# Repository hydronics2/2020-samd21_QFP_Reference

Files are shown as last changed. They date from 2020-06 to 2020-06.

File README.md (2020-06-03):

# samd21_QFP_reference_PCB - based on the Adafruit ItsyBitsy M0

This is a reference design for a SAMD21 for easy SWD programming and testing.  This is a copy of the [Adafruit itsyBitsy m0](https://www.adafruit.com/product/3727)... Using the SAMD21G QFP package among other small part changes. It does not include the memory module for circuit python use. This is similar to the other QFP packages with less memory that I was working with [here](https://github.com/hydronics2/samd21_QFP_reference_PCB).

The QFP package is pretty easy to solder and gives you about the same amount of pins as the original Aruduino 328P.

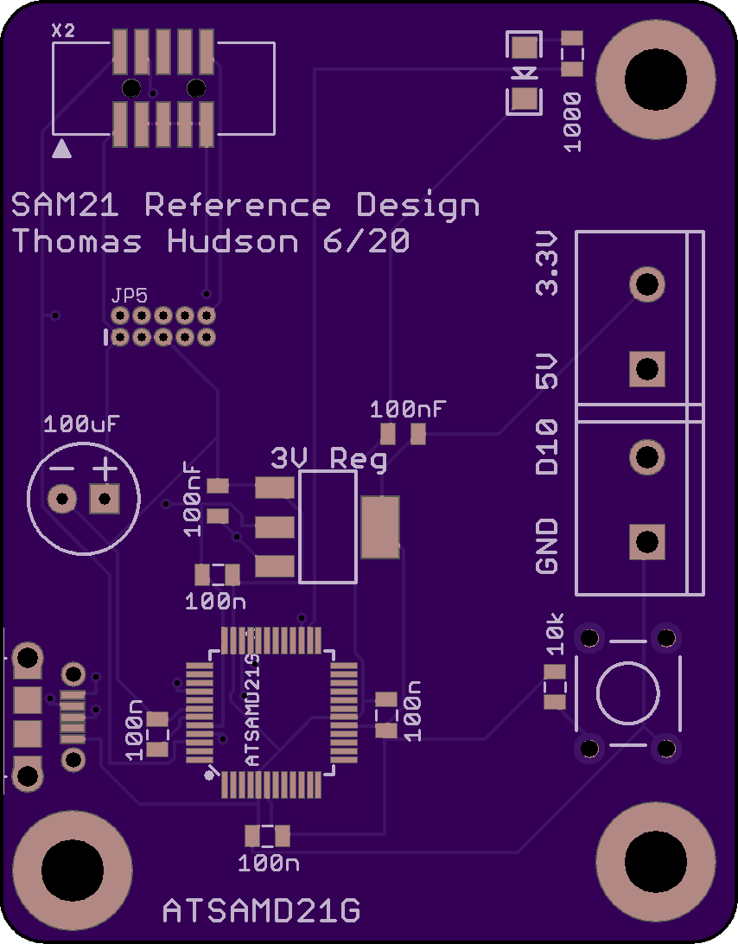
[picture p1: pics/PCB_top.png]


You can order boards from Oshpark using this link: [project](https://oshpark.com/shared_projects/W1OeQO5j)

Here's a list of parts:
- ATSAMD21G from [digikey](https://www.digikey.com/product-detail/en/microchip-technology/ATSAMD21G18A-AUT/ATSAMD21G18A-AUTCT-ND/4878879).
  -	ARM® Cortex®-M0+ SAM D21G Microcontroller IC 32-Bit 48MHz 256KB (256K x 8) FLASH 48-TQFP (7x7)
- 10 pin SWD Header
  - I included an SMD version [mouser](https://www.mouser.com/ProductDetail/485-752)
  - an even cooler SMD version [mouser](https://www.mouser.com/ProductDetail/485-4048)
  - and a through hole version [mouser](https://www.mouser.com/ProductDetail/200-SHF10501LDTH)
- 3.3V Regulator - generic (18V max input) [mouser](https://www.mouser.com/ProductDetail/511-LDL1117S50R)
- USB micro connector [digikey](https://www.digikey.com/product-detail/en/amphenol-icc-fci/10118194-0001LF/609-4618-1-ND/2785382)
- generic 6mmx6mm tactile button [sparkfun](https://www.sparkfun.com/products/97)
- screw terminal 5mm pitch [sparkfun](https://www.sparkfun.com/products/8432) or [aliexpress](https://www.aliexpress.com/wholesale?catId=0&initiative_id=SB_20190221221755&SearchText=pcb+screw+terminal)

SWD Programmer/Debugger: [Segger](https://www.digikey.com/product-detail/en/segger-microcontroller-systems/8.08.91-J-LINK-EDU-MINI/899-1061-ND/7387472)

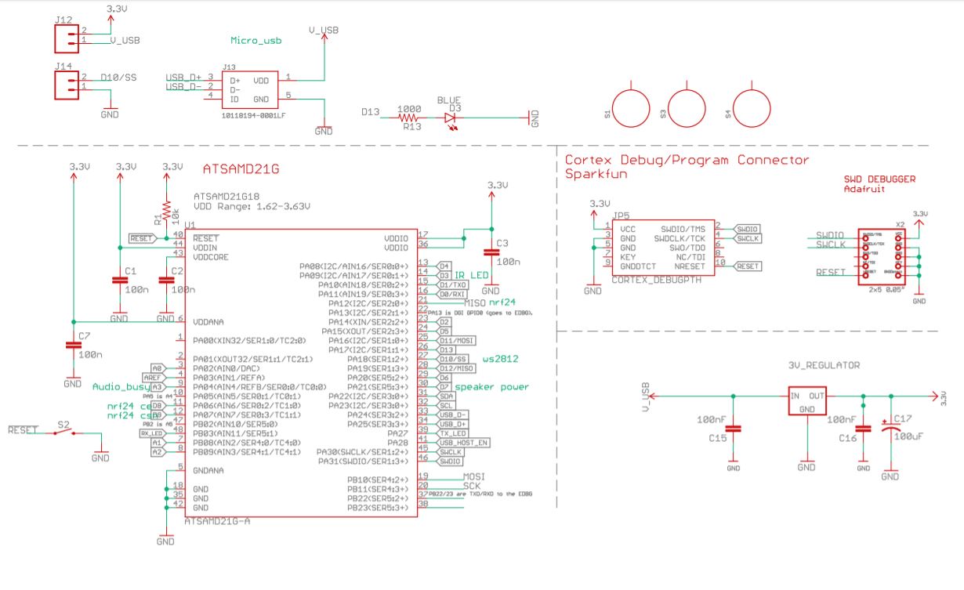
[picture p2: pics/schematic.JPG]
schematic


## Programming

Adafruit has provided a great [tutorial](https://learn.adafruit.com/how-to-program-samd-bootloaders) for flashing the bootloader onto the board using the segger SWD programmer. It's easier than it looks.

You probably already have the bootloader loader on your computer! Arduino installs them when you install the board files.

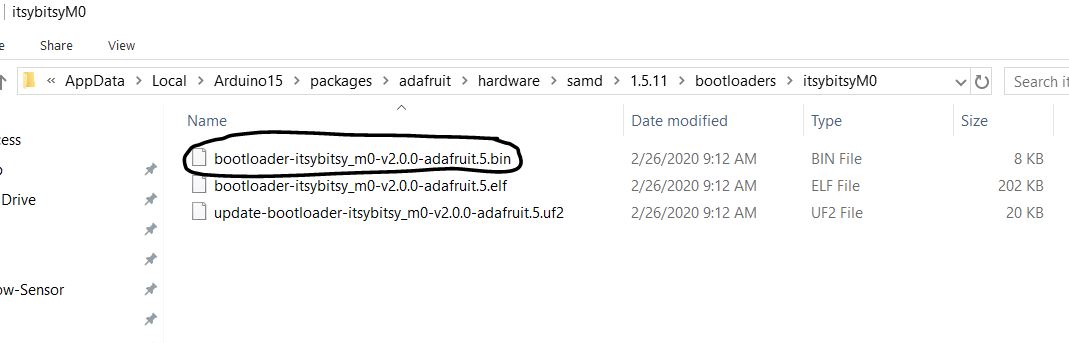
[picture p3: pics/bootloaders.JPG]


# Projects - Pickathon Music Festival

I completed a project at [Pickathon 2019 music festival](https://www.instagram.com/p/B0nMJXHBQjl/) using radio modules and MP3 Players that socketed into a PCB very similar to the reference design above.

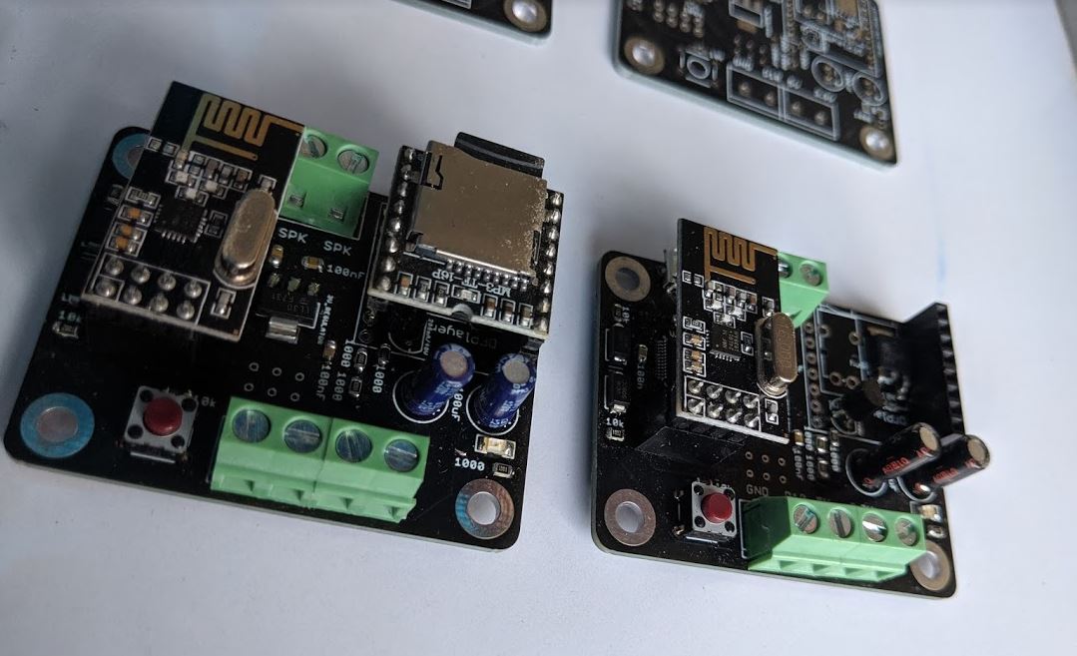
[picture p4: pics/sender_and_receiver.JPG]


Both the sender and receiver boards had radio modules socketed into an SPI header that was exposed via a 8-pin header.
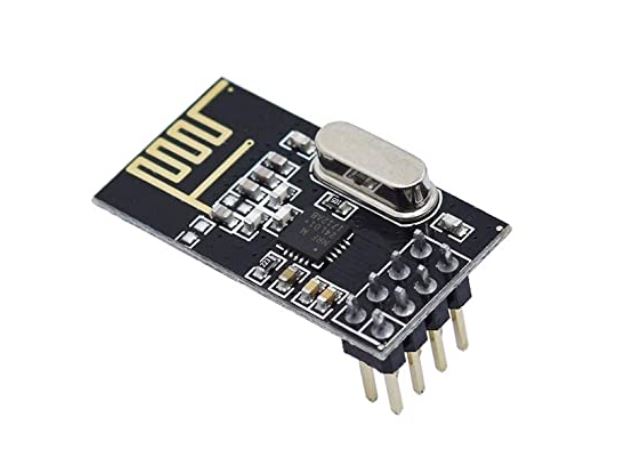
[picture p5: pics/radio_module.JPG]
radio


Each receiver board had a mini-MP3 module. When triggered, the MP3 modules output recorded poetry files to small speakers. The MP3 modules worked really well. The 3-watt amplifier sounded pretty good with small speakers in quiet spaces.
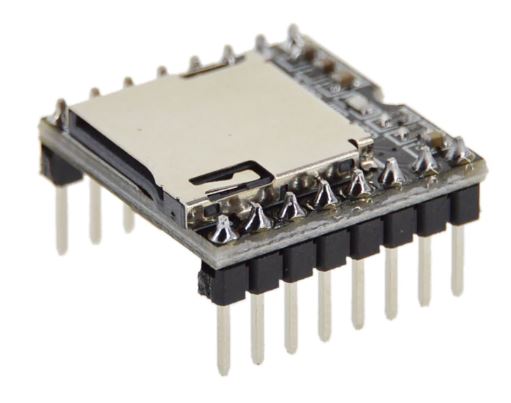
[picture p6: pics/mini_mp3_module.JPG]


## Parts list
- generic Radio module Arduino NRF24L01+ 2.4GHz Wireless RF [amazon](https://www.amazon.com/gp/product/B07GZ17ZWS/ref=ppx_yo_dt_b_asin_title_o01_s00?ie=UTF8&psc=1)
- generic Mini-MP3 module [aliexpress](https://www.aliexpress.com/item/32787304159.html?spm=a2g0s.9042311.0.0.27424c4dwHyDU7)

## Programming

The radio module library is here:
- include <nRF24L01.h>  //https://github.com/nRF24/RF24

The MP3 radio module is here:
- include <DFPlayerMini_Fast.h>  //https://github.com/PowerBroker2/DFPlayerMini_Fast

I slightly modified the DFPlayerMini library so it would work with hardware serial and not software serial as it was originally designed.

The micro-controller communicated with the MP3 player using serial RX/TX.

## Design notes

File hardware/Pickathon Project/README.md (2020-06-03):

## Pickathon Hardware

Instead of including a standard SWD programming header, I only exposed the pins at places that would except a custom programming PCB with pogo pins..... so this PCB design (as-is) is probably  not useful to anyone but easy to manipulate.

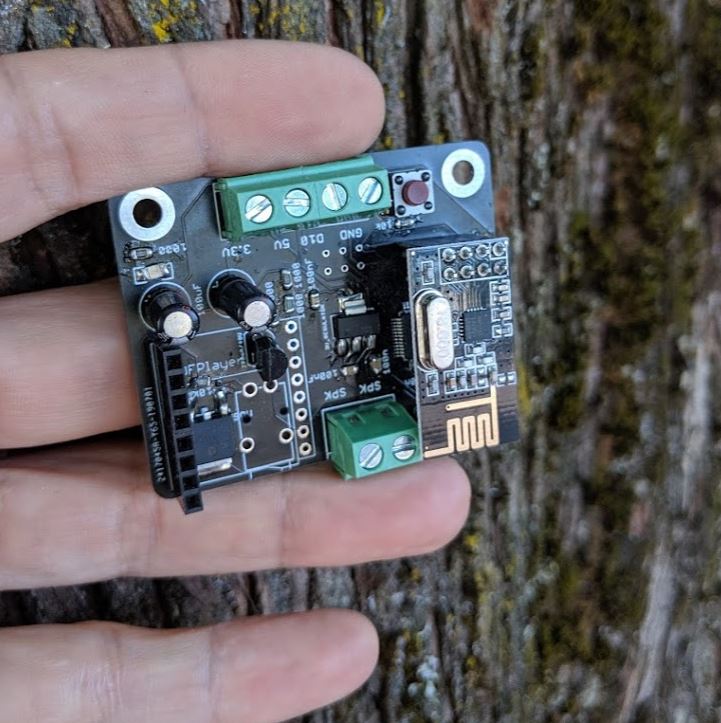
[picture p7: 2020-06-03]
pics/sender_module.JPG

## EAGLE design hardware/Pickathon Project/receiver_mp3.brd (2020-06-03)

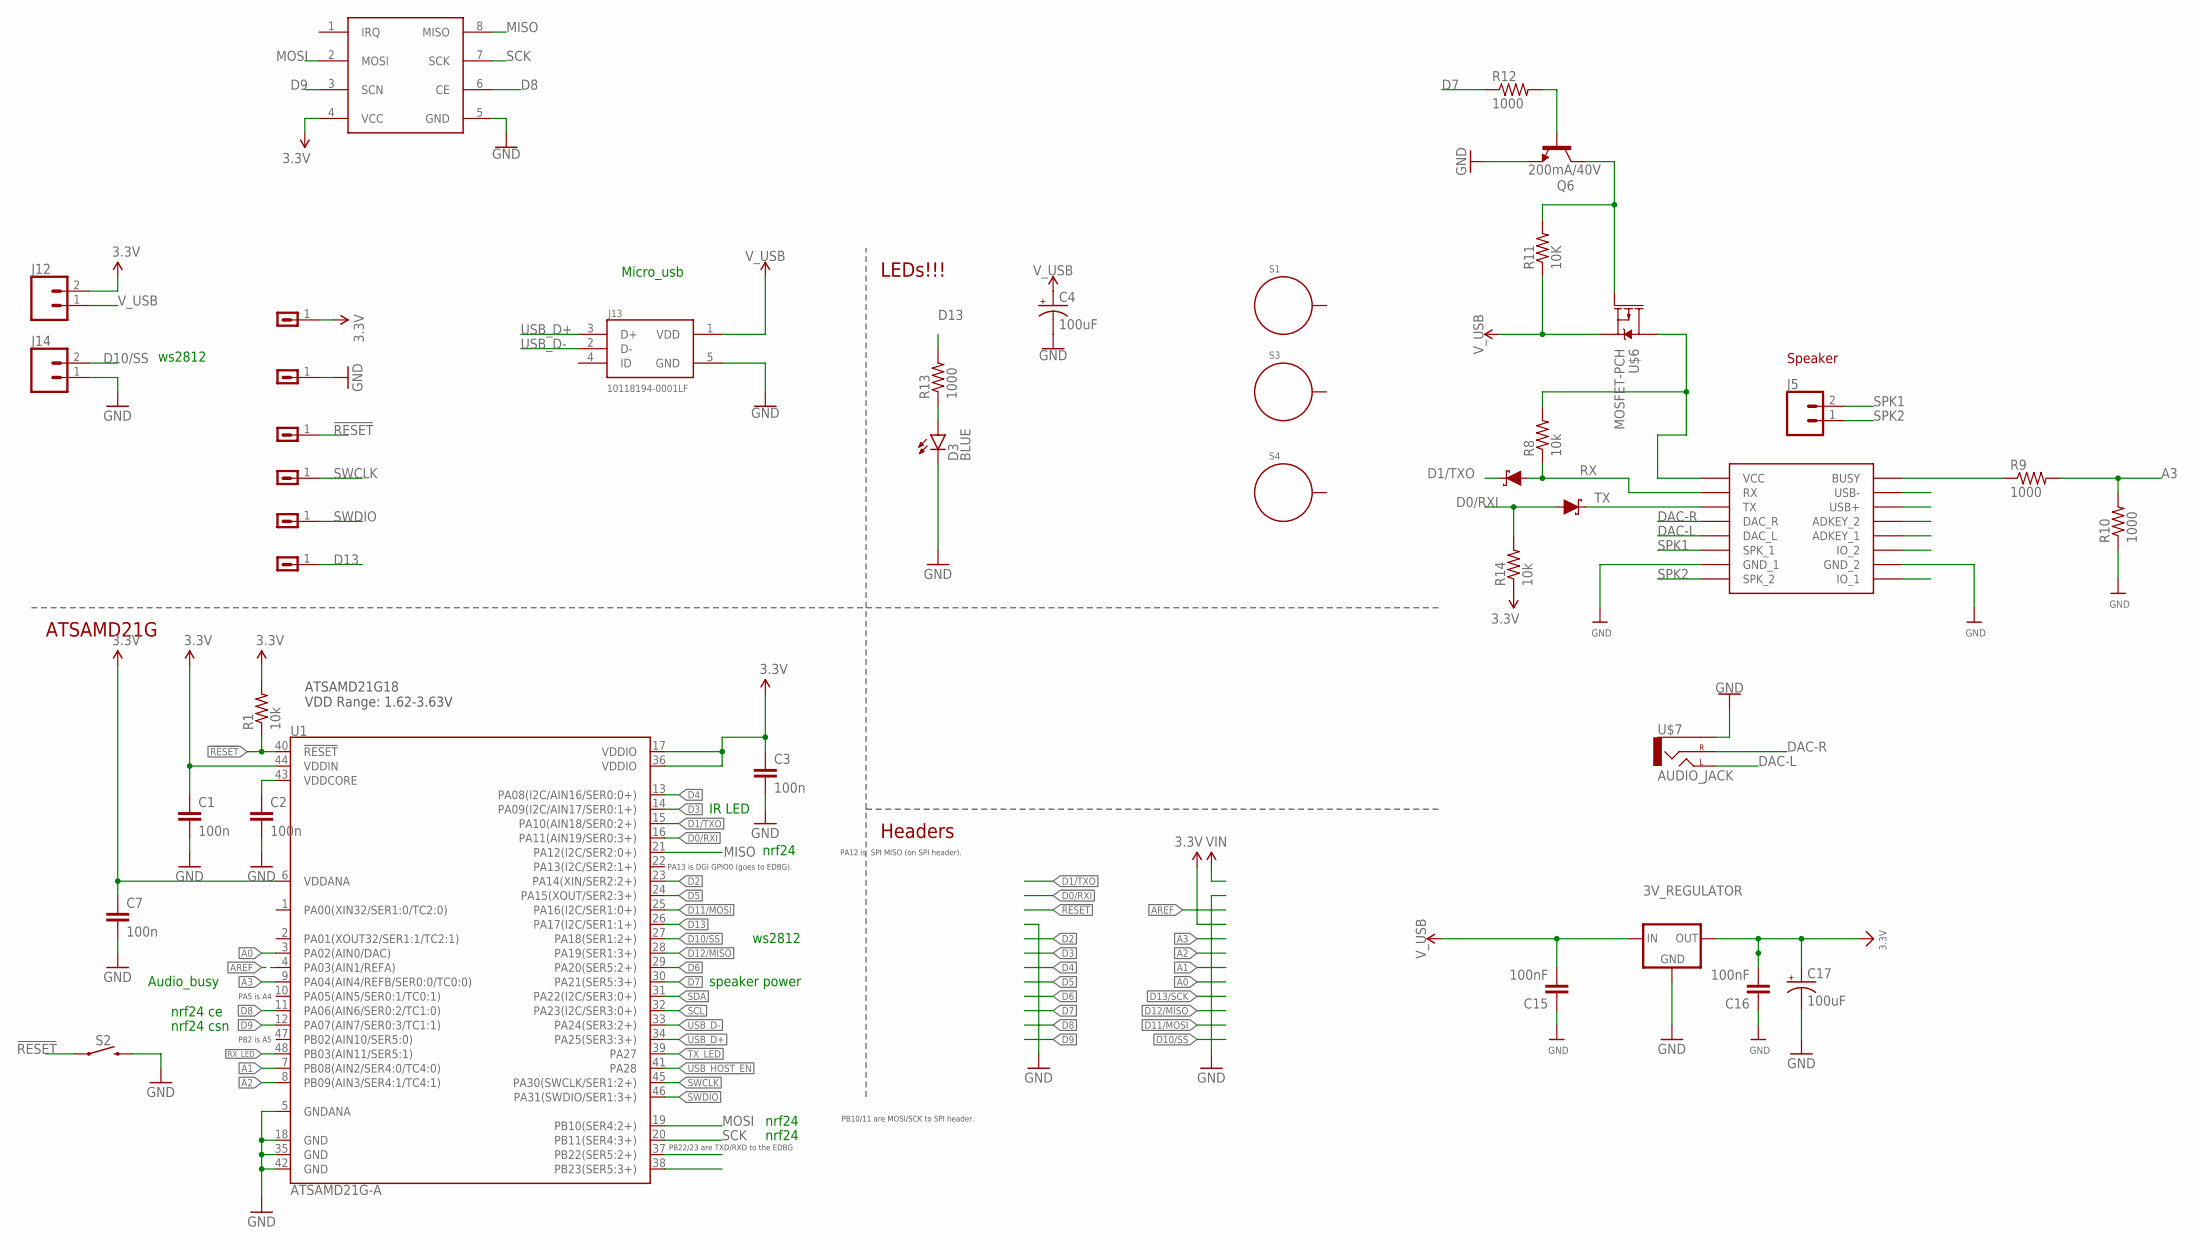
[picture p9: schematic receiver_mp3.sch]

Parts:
3V_REGULATOR: LDL1117_5V_REG; SOT223
C1, C2, C3, C7: 100n; 0805
C4, C17: 100uF; CPOL-RADIAL-2.5MM-6.5MM
C15, C16: 100nF; 0805
D1, D5: 3A/40V/500mV; SMA-DIODE
D3: BLUE; LED-1206
J5, J12, J14: CONN_025MM; SCREWTERMINAL-5MM-2
J13: 10118194-0001LF; FRAMATOME_10118194-0001LF
Q6: 200mA/40V; TO-92-EZ
R1, R8, R14: 10k; 0805
R9, R10, R12, R13: 1000; 0805
R11: 10K; 0805
S1, S3, S4: STANDOFF_ELECTRICAL144; STANDOFF_ELECTRICAL_144MILL_NORMAL_SCREW
S2: MOMENTARY-SWITCH-SPST-PTH-6.0MM-KIT; TACTILE_SWITCH_PTH_6.0MM_KIT
U1: ATSAMD21G-A; TQFP-48
U$1: DFPLAYER
U$3: NRF24L01
U$6: MOSFET-PCH; DPAK
U$7: AUDIO_JACK; 1/8"AUDIO_JACK
U$8, U$13, U$18, U$19, U$20, U$22: CONN_011.27MM; 1X01-1.27MM

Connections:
3.3V: 3V_REGULATOR.2 (OUT), 3V_REGULATOR.4 (OUT), C1.1, C3.1, C7.1, C16.2, C17.1 (+), J12.2, R1.2, R14.1, U1.6 (VDDANA), U1.17 (VDDIO), U1.36 (VDDIO), U1.44 (VDDIN), U$3.4 (VCC), U$18.1
!RESET: R1.1, S2.1, U1.40 (!RESET!), U$20.1
A0: U1.3 (PA02(AIN0/DAC))
A1: U1.7 (PB08(AIN2/SER4:0/TC4:0))
A2: U1.8 (PB09(AIN3/SER4:1/TC4:1))
A3: R9.2, R10.2, U1.9 (PA04(AIN4/REFB/SER0:0/TC0:0))
AREF: U1.4 (PA03(AIN1/REFA))
D0/RXI: D5.A, R14.2, U1.16 (PA11(AIN19/SER0:3+))
D1/TXO: D1.C, U1.15 (PA10(AIN18/SER0:2+))
D2: U1.23 (PA14(XIN/SER2:2+))
D3: U1.14 (PA09(I2C/AIN17/SER0:1+))
D4: U1.13 (PA08(I2C/AIN16/SER0:0+))
D5: U1.24 (PA15(XOUT/SER2:3+))
D6: U1.29 (PA20(SER5:2+))
D7: R12.1, U1.30 (PA21(SER5:3+))
D8: U1.11 (PA06(AIN6/SER0:2/TC1:0)), U$3.6 (CE)
D9: U1.12 (PA07(AIN7/SER0:3/TC1:1)), U$3.3 (SCN)
D10/SS: J14.2, U1.27 (PA18(SER1:2+))
D11/MOSI: U1.25 (PA16(I2C/SER1:0+))
D12/MISO: U1.28 (PA19(SER1:3+))
D13: R13.2, U1.26 (PA17(I2C/SER1:1+)), U$8.1
DAC-L: U$1.DAC_L, U$7.LEFT_TIP_1 (LEFT)
DAC-R: U$1.DAC_R, U$7.RIGHT
GND: 3V_REGULATOR.1 (GND), C1.2, C2.2, C3.2, C4.2 (-), C7.2, C15.1, C16.1, C17.2 (-), D3.C, J13.5 (GND), J14.1, Q6.1 (E), R10.1, S2.3 (2), U1.5 (GNDANA), U1.18 (GND), U1.35 (GND), U1.42 (GND), U$1.GND_1, U$1.GND_2, U$3.5 (GND), U$7.GND (SLEEVE), U$13.1
INT1: U1.38 (PB23(SER5:3+))
MISO: U1.21 (PA12(I2C/SER2:0+)), U$3.8 (MISO)
MOSI: U1.19 (PB10(SER4:2+)), U$3.2 (MOSI)
unnamed: R8.2, U$1.VCC, U$6.4 (D)
unnamed: D3.A, R13.1
unnamed: Q6.3 (C), R11.2, U$6.1 (G)
unnamed: Q6.2 (B), R12.2
unnamed: R9.1, U$1.BUSY
RX: D1.A, R8.1, U$1.RX
RX_LED: U1.48 (PB03(AIN11/SER5:1))
SCK: U1.20 (PB11(SER4:3+)), U$3.7 (SCK)
SCL: U1.32 (PA23(I2C/SER3:0+))
SDA: U1.31 (PA22(I2C/SER3:0+))
SPK1: J5.2, U$1.SPK1 (SPK_1)
SPK2: J5.1, U$1.SPK2 (SPK_2)
SWCLK: U1.45 (PA30(SWCLK/SER1:2+)), U$22.1
SWDIO: U1.46 (PA31(SWDIO/SER1:3+)), U$19.1
TX: D5.C, U$1.TX
TX_LED: U1.39 (PA27)
USB_D+: J13.3 (D+), U1.34 (PA25(SER3:3+))
USB_D-: J13.2 (D-), U1.33 (PA24(SER3:2+))
USB_HOST_EN: U1.41 (PA28)
VDDCORE: C2.1, U1.43 (VDDCORE)
V_USB: 3V_REGULATOR.3 (IN), C4.1 (+), C15.2, J12.1, J13.1 (VDD), R11.1, U$6.3 (S)

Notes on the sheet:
PB22/23 are TXD/RXD to the EDBG
PB10/11 are MOSI/SCK to SPI header.
PA12 is SPI MISO (on SPI header).
PA13 is DGI GPIO0 (goes to EDBG).
PA5 is A4
PB2 is A5
LEDs!!!
Headers
ATSAMD21G
ATSAMD21G18 VDD Range: 1.62-3.63V
Micro_usb
IR LED
speaker power
Speaker
Audio_busy
ws2812
nrf24
nrf24 csn
nrf24 ce

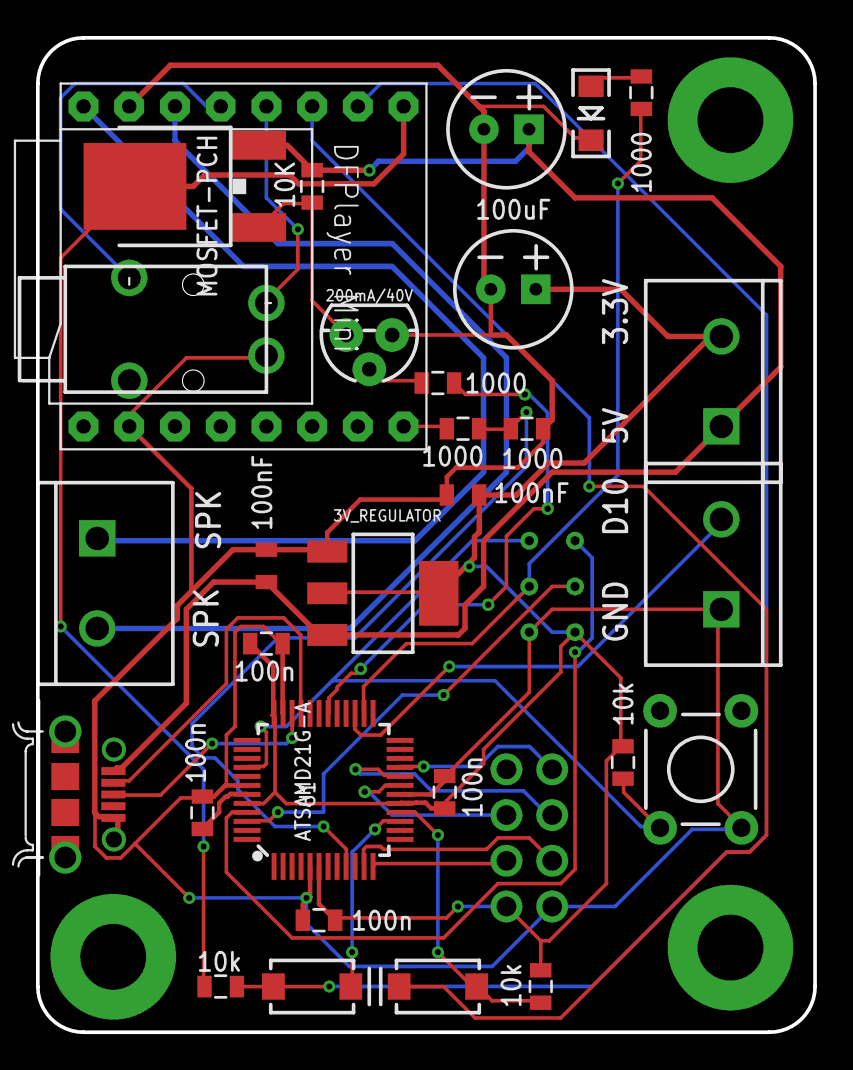
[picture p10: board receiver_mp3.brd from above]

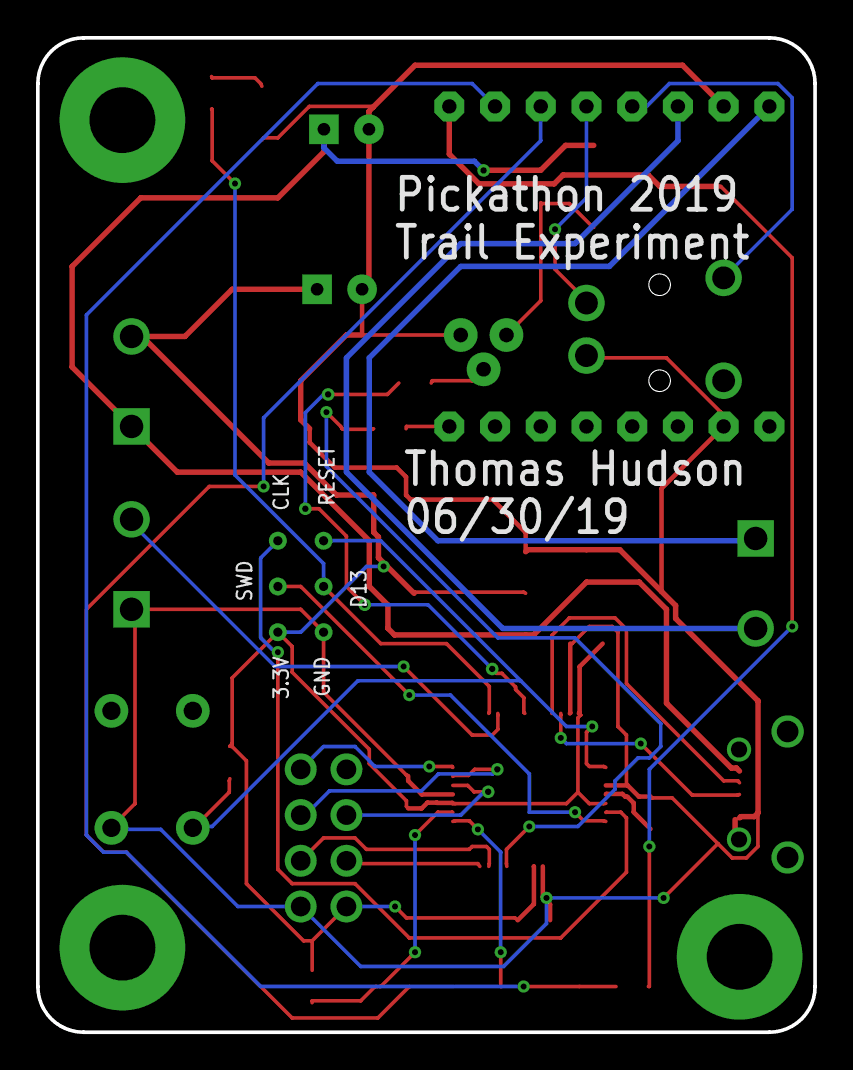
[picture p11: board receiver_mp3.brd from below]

Board: 2 copper layers, 43.2 x 55.2 mm, 40 parts (6 on the bottom side), 31 nets.

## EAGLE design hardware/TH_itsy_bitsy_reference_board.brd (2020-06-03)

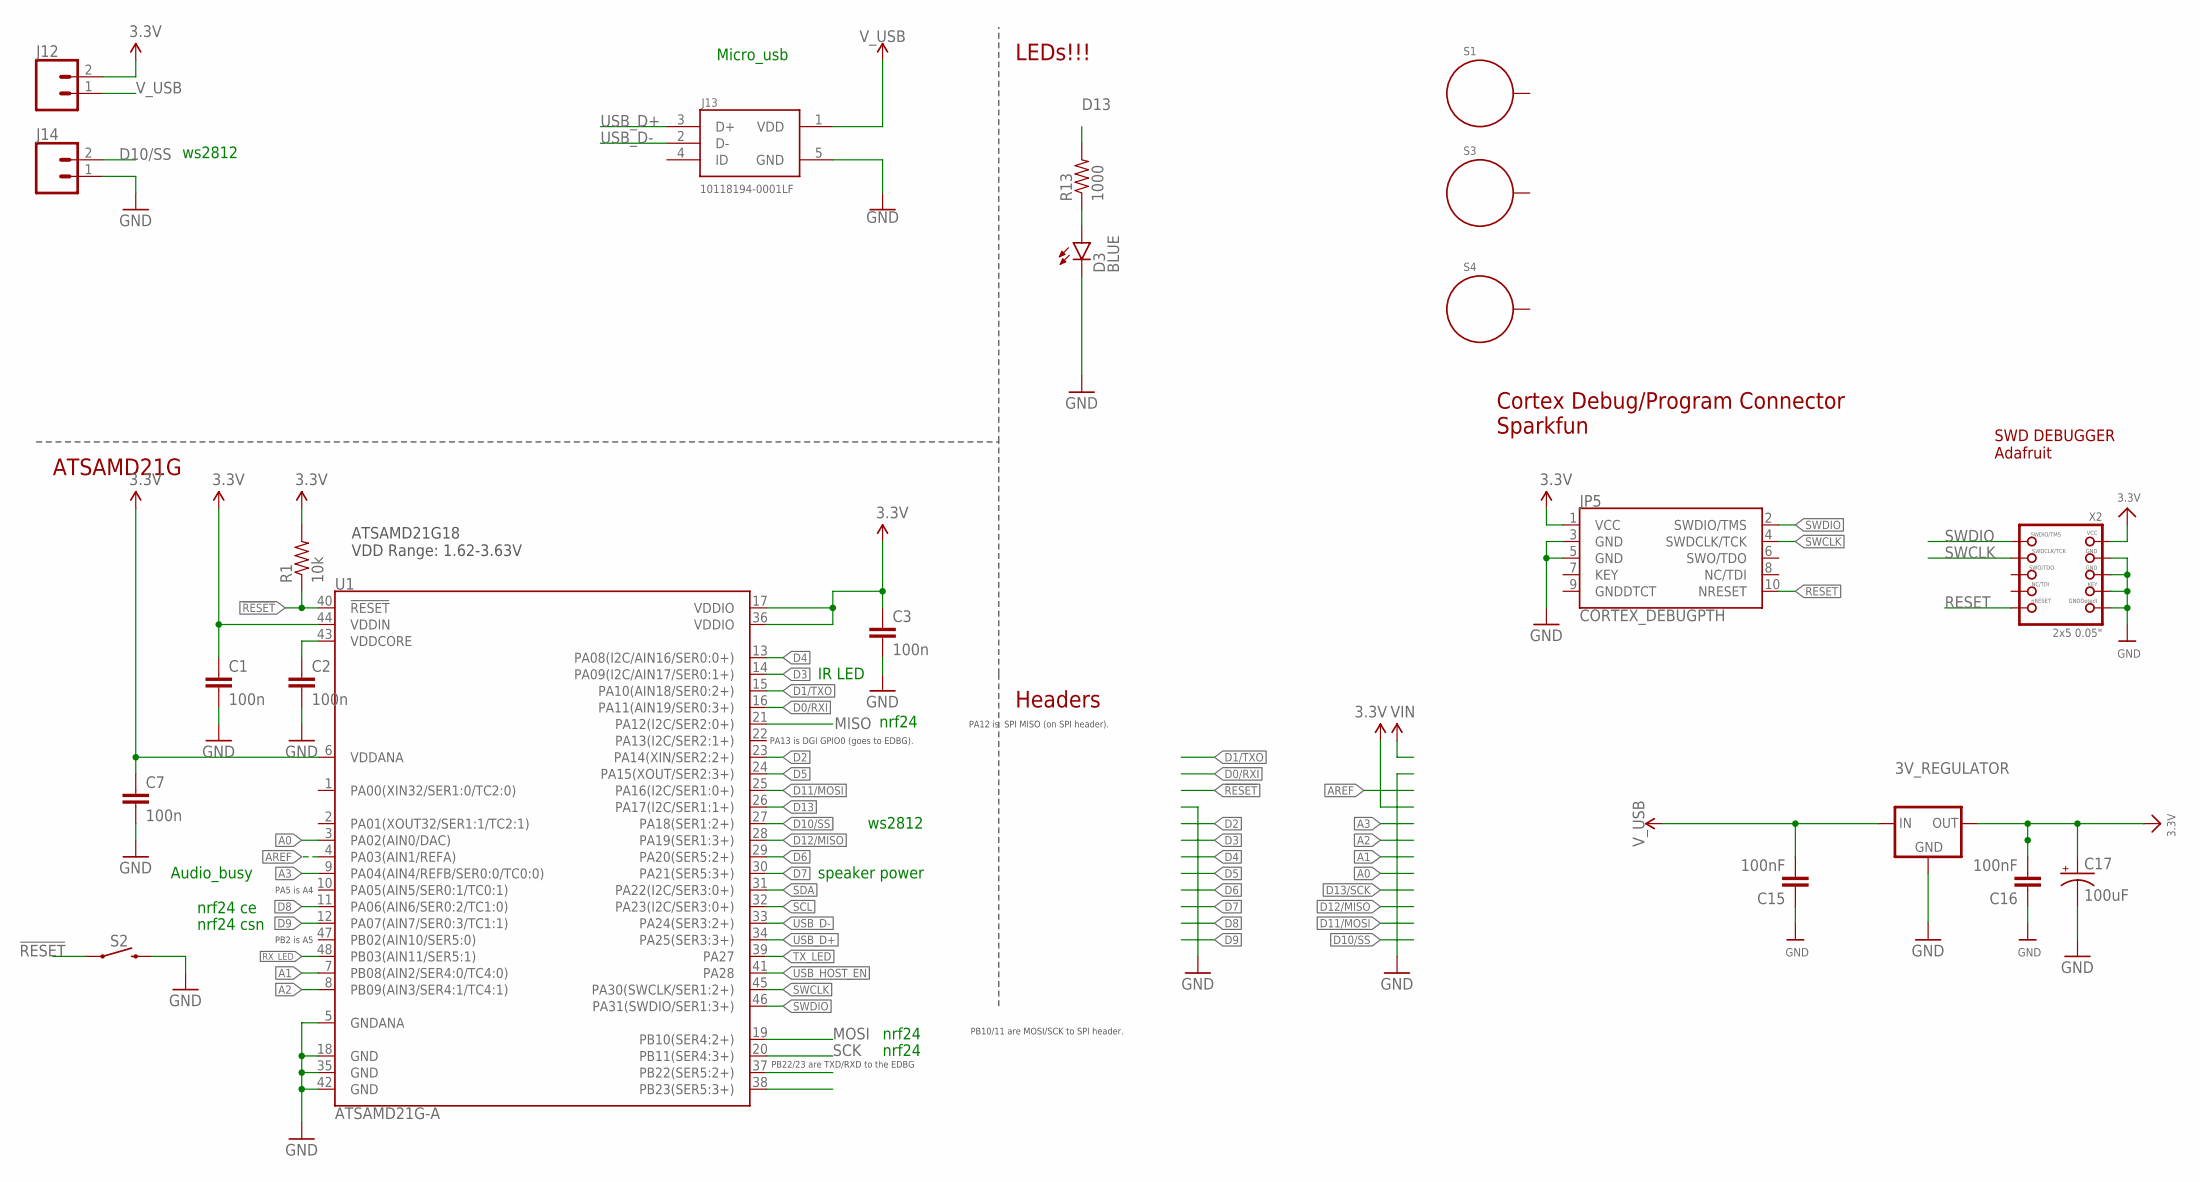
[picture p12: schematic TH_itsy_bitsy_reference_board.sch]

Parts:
3V_REGULATOR: LDL1117_5V_REG; SOT223
C1, C2, C3, C7: 100n; 0805
C15, C16: 100nF; 0805
C17: 100uF; CPOL-RADIAL-2.5MM-6.5MM
D3: BLUE; LED-1206
J12, J14: CONN_025MM; SCREWTERMINAL-5MM-2
J13: 10118194-0001LF; FRAMATOME_10118194-0001LF
JP5: CORTEX_DEBUGPTH; 2X5-PTH-1.27MM
R1: 10k; 0805
R13: 1000; 0805
S1, S3, S4: STANDOFF_ELECTRICAL144; STANDOFF_ELECTRICAL_144MILL_NORMAL_SCREW
S2: MOMENTARY-SWITCH-SPST-PTH-6.0MM-KIT; TACTILE_SWITCH_PTH_6.0MM_KIT
U1: ATSAMD21G-A; TQFP-48
X2: 2x5 0.05"; 2X05_1.27MM_BOX_POSTS

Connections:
3.3V: 3V_REGULATOR.2 (OUT), 3V_REGULATOR.4 (OUT), C1.1, C3.1, C7.1, C16.2, C17.1 (+), J12.2, JP5.1 (VCC), R1.2, U1.6 (VDDANA), U1.17 (VDDIO), U1.36 (VDDIO), U1.44 (VDDIN), X2.1 (VCC)
!RESET: R1.1, S2.1, U1.40 (!RESET!)
A0: U1.3 (PA02(AIN0/DAC))
A1: U1.7 (PB08(AIN2/SER4:0/TC4:0))
A2: U1.8 (PB09(AIN3/SER4:1/TC4:1))
A3: U1.9 (PA04(AIN4/REFB/SER0:0/TC0:0))
AREF: U1.4 (PA03(AIN1/REFA))
D0/RXI: U1.16 (PA11(AIN19/SER0:3+))
D1/TXO: U1.15 (PA10(AIN18/SER0:2+))
D2: U1.23 (PA14(XIN/SER2:2+))
D3: U1.14 (PA09(I2C/AIN17/SER0:1+))
D4: U1.13 (PA08(I2C/AIN16/SER0:0+))
D5: U1.24 (PA15(XOUT/SER2:3+))
D6: U1.29 (PA20(SER5:2+))
D7: U1.30 (PA21(SER5:3+))
D8: U1.11 (PA06(AIN6/SER0:2/TC1:0))
D9: U1.12 (PA07(AIN7/SER0:3/TC1:1))
D10/SS: J14.2, U1.27 (PA18(SER1:2+))
D11/MOSI: U1.25 (PA16(I2C/SER1:0+))
D12/MISO: U1.28 (PA19(SER1:3+))
D13: R13.2, U1.26 (PA17(I2C/SER1:1+))
GND: 3V_REGULATOR.1 (GND), C1.2, C2.2, C3.2, C7.2, C15.1, C16.1, C17.2 (-), D3.C, J13.5 (GND), J14.1, JP5.3 (GND), JP5.5 (GND), S2.3 (2), U1.5 (GNDANA), U1.18 (GND), U1.35 (GND), U1.42 (GND), X2.3 (GND), X2.5 (GND), X2.7 (KEY), X2.9 (GNDDETECT)
INT1: U1.38 (PB23(SER5:3+))
MISO: U1.21 (PA12(I2C/SER2:0+))
MOSI: U1.19 (PB10(SER4:2+))
unnamed: D3.A, R13.1
RESET: JP5.10 (NRESET), X2.10 (NRESET)
RX_LED: U1.48 (PB03(AIN11/SER5:1))
SCK: U1.20 (PB11(SER4:3+))
SCL: U1.32 (PA23(I2C/SER3:0+))
SDA: U1.31 (PA22(I2C/SER3:0+))
SWCLK: JP5.4 (SWDCLK/TCK), U1.45 (PA30(SWCLK/SER1:2+)), X2.4 (SWDCLK)
SWDIO: JP5.2 (SWDIO/TMS), U1.46 (PA31(SWDIO/SER1:3+)), X2.2 (SWDIO)
TX_LED: U1.39 (PA27)
USB_D+: J13.3 (D+), U1.34 (PA25(SER3:3+))
USB_D-: J13.2 (D-), U1.33 (PA24(SER3:2+))
USB_HOST_EN: U1.41 (PA28)
VDDCORE: C2.1, U1.43 (VDDCORE)
V_USB: 3V_REGULATOR.3 (IN), C15.2, J12.1, J13.1 (VDD)

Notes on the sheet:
PB22/23 are TXD/RXD to the EDBG
PB10/11 are MOSI/SCK to SPI header.
PA12 is SPI MISO (on SPI header).
PA13 is DGI GPIO0 (goes to EDBG).
PA5 is A4
PB2 is A5
LEDs!!!
Headers
ATSAMD21G
ATSAMD21G18 VDD Range: 1.62-3.63V
Micro_usb
IR LED
speaker power
Audio_busy
ws2812
nrf24
nrf24 csn
nrf24 ce
SWD DEBUGGER Adafruit
Cortex Debug/Program Connector Sparkfun

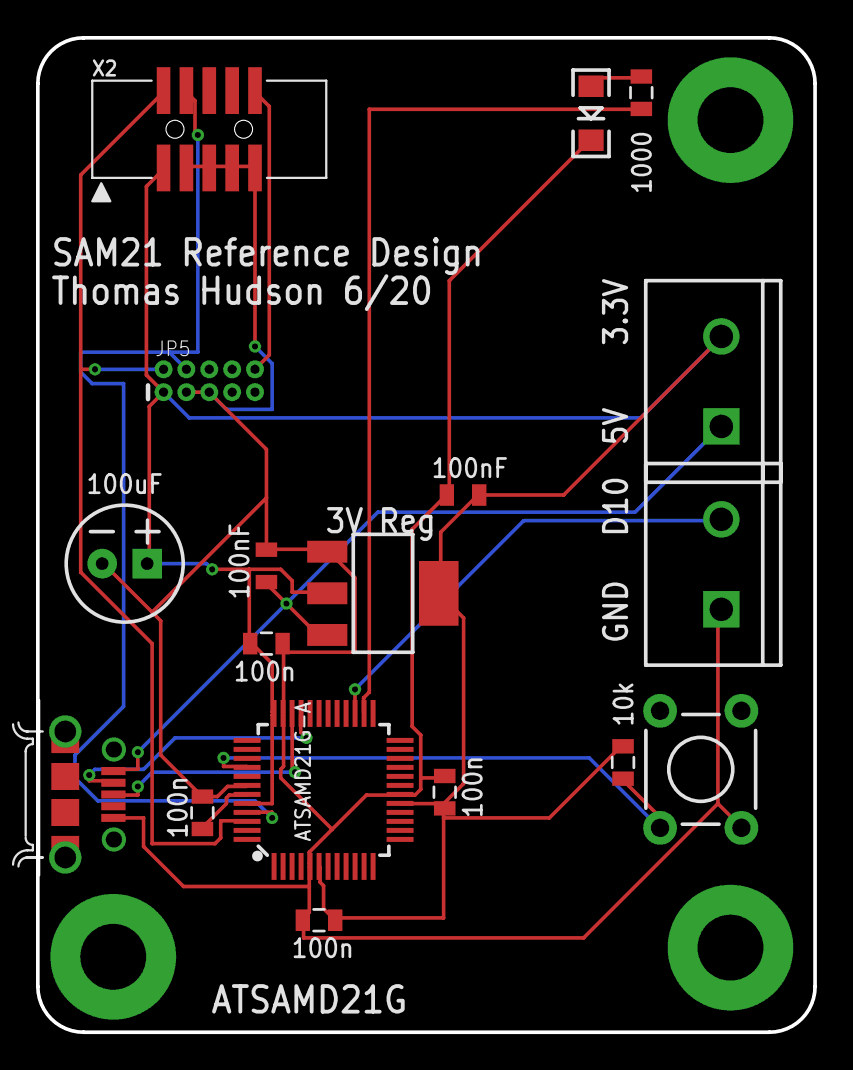
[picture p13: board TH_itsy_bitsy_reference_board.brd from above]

Board: 2 copper layers, 43.2 x 55.2 mm, 21 parts (0 on the bottom side), 13 nets.

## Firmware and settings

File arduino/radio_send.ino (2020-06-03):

const int playerNumber = 0; //speaker 0, 1st speaker


#include <SPI.h>
#include <nRF24L01.h>  //https://github.com/nRF24/RF24
#include <RF24.h>

#include <DFPlayerMini_Fast.h>  //https://github.com/PowerBroker2/DFPlayerMini_Fast

DFPlayerMini_Fast myMP3; 

RF24 radio(8,9); //CE and CSN

const byte address[6] = "00001";
const int motionSensorPin = 10;
const int mp3PowerPin = 7;
const int led = 13;

//poem info... indicates the SD card file number for each poem.. 
int poemInfo [][8] = {  {1,2,3,4,5,6,0,0}, //time for bed - 6 lines 
                        {7,8,9,10,11,0,0,0}, //oleander - 5 lines 
                        {12,13,14,15,0,0,0,0}, // its cool - 4 lines 
                        {16,17,18,19,20,21,0,0}, //tonight I could do anything - 6 lines
                        {22, 23, 24, 25, 26, 27, 0, 0}, //you're a bird to the treasure - 6 lines
                        {28,29,30,31,32,33, 0, 0}, //tamborine - 6 lines
                        {34,35,36,37,38,39, 0, 0}, //wildfire
                        {40,41,42,43,44,45, 0, 0}, //william berry
                        
};

int poemSectionDelays [][8] = { {3000,3000,3000,3000,3000,3000,0,0}, //time for bed - 6 lines 
                                {3000,3000,3000,3000,3000,0,0,0}, //oleander - 5 lines 
                                {3000,3000,3000,3000,0,0,0,0}, // its cool - 4 lines 
                                {12000,8000,7000,5000,4000,4000,0,0}, //tonight I could do anything
                                {2000,5000,5000,6000,6000,5000,0,0}, //you're a bird to the treasure
                                {8000,3000,7000,12000,11000,8000,0,0}, //tamborine
                                {4000,15000,12000,23000,4000,11000,0,0}, //wildfire
                                {11000,13000,8000,8000,8000,12000,0,0}, //william berry
};

//                                     1     2     3     4   5
byte poemSectionStartDelays [][6] = { {0x4, 0x7, 0x0A, 0x0D, 0x10, 0x0}, //time for bed - 6 lines 
                                      {0x4, 0x7, 0x8, 0x9, 0x0, 0x0}, //oleander - 5 lines 
                                      {0X4, 0x6, 0x8, 0x0, 0x0, 0x0}, // its cool - 4 lines 
                                      {0x0B, 0x13, 0x18, 0x1B, 0x1E, 0x0}, //tonight I could do anything
                                      {0x3, 0x7, 0x0A, 0x0E, 0x13, 0x0}, //you're a bird to the treasure
                                      {0x8, 0x0A, 0x10, 0x19, 0x22, 0x0}, //tamborine                                      
                                      {0x4, 0x11, 0x1B, 0x31, 0x33, 0x0}, //wildfire
                                      
                                      {0x0B, 0x15, 0x1C, 0x23, 0x2A, 0x0}, //william berry
};

int poemLength [] = { 20000, //time for bed
                      12000, //oleander
                      11000, //it's cool, its cool
                      35000, //tonight I could do anything
                      25000, // you're a bird to the treasure
                      43000, //tamborine
                      62000, //wildfire
                      57000, //william berry
                      };

byte poemNumber = 0;
byte messageNumber = 1;


void setup() {
  Serial.begin(115200);

  Serial.println("starting");
  pinMode(led, OUTPUT);
  pinMode(motionSensorPin, INPUT);
  
  radio.begin();
  radio.openWritingPipe(address);
  radio.setPALevel(RF24_PA_MAX);
  radio.setDataRate(RF24_250KBPS);
  radio.stopListening();

  Serial1.begin(9600); //mp3 player communication
  myMP3.begin(Serial1);
  pinMode(mp3PowerPin, OUTPUT); //power pin
  digitalWrite(mp3PowerPin, HIGH);
  delay(800);
  myMP3.volume(30);
  delay(50);
  digitalWrite(mp3PowerPin, LOW);

  randomSeed(analogRead(0));
  poemNumber = random(0,4);

  
}


long lastTimeSent = -30000;
int fileToPlay = 0;

void loop() 
{
  long currentTime = millis();

  int motionSensor = digitalRead(motionSensorPin);

  int delayBeforeNextPoem = poemLength[poemNumber];
  
  if(currentTime - lastTimeSent > delayBeforeNextPoem && motionSensor)
  {
    lastTimeSent = currentTime;

    messageNumber++;
    if(messageNumber == 254) messageNumber = 1;

    
    if(poemNumber == 4) poemNumber = 1;
    else if(poemNumber == 1) poemNumber = 3;
    else if(poemNumber == 3) poemNumber = 7;
    else if(poemNumber == 7) poemNumber = 5;
    else if(poemNumber == 5) poemNumber = 0;
    else if(poemNumber == 0) poemNumber = 2;
    else if(poemNumber == 2) poemNumber = 6;
    else if(poemNumber == 6) poemNumber = 4;
    
    //poemNumber = 7;
    const char message[] = {messageNumber, poemNumber, poemSectionStartDelays[poemNumber][0], poemSectionStartDelays[poemNumber][1], poemSectionStartDelays[poemNumber][2], poemSectionStartDelays[poemNumber][3], poemSectionStartDelays[poemNumber][4], poemSectionStartDelays[poemNumber][5]} ;
    
    for(int i = 0; i < sizeof(message); i++)
    {
      Serial.print(message[i], HEX);
      Serial.print(", ");
    }
    Serial.println();
    radio.write(&message, sizeof(message));
    delay(50);
    radio.write(&message, sizeof(message));
    delay(50);
    radio.write(&message, sizeof(message));
    delay(50);
    
    digitalWrite(mp3PowerPin, HIGH);    
    fileToPlay = poemInfo [poemNumber][playerNumber];
    delay(800);
    myMP3.volume(30);
    delay(50);
    myMP3.play(fileToPlay);
    delay(poemSectionDelays [poemNumber][playerNumber]);
    digitalWrite(mp3PowerPin, LOW);
  }

}

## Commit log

2020-06-03 copy from samd21-qfp
    [arduino_zero.cfg, samd21_QFP_reference.brd, samd21_QFP_reference.sch]
2020-06-03 adjusted to reflect samd21 itsybitsy
    [TH_itsy_bitsy_reference_board.brd, TH_itsy_bitsy_reference_board.sch, samd21_QFP_reference.brd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]
2020-06-03 deleted old files
    [arduino_zero.cfg]
2020-06-03 added hardware and software for Pickathon
    [receiver_mp3.brd, receiver_mp3.sch]

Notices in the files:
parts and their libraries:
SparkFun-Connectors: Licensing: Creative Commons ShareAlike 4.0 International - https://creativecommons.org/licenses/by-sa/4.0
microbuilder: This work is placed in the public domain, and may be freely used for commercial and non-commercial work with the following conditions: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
